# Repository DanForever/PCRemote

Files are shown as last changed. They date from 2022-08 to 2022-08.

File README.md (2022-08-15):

# Remote control ATX power switch

An alternative, Internet of things (IoT) approach to Wake-on-Lan (WoL).

This is a device that you plug into a free USB2 motherboard header in order to draw power (assuming that your motherboard continues to provides power to the USB headers when turned off), and sits inbetween the motherboard front panel IO header and your case.
It will connect to your wifi, and you can access it using your web browser, and press a button to remote turn your PC on or off.

This was created for people for whom WoL isn't an option, but need to be able to check and control the power status of their PC remotely (such as people that work from home using some form of remote desktop software).

WoL works by broadcasting a special packet containing the mac address of the PC you want to turn on. Until your PC starts responding to normal requests, you don't actually know if the WoL packet worked or not, and you have no way of checking if your PC is functioning.
This device on the other hand, can tell you at a glance if your PC is on or off. There's less ambiguity involved.

## Prototype
This is the first prototype, made entirely using THT parts
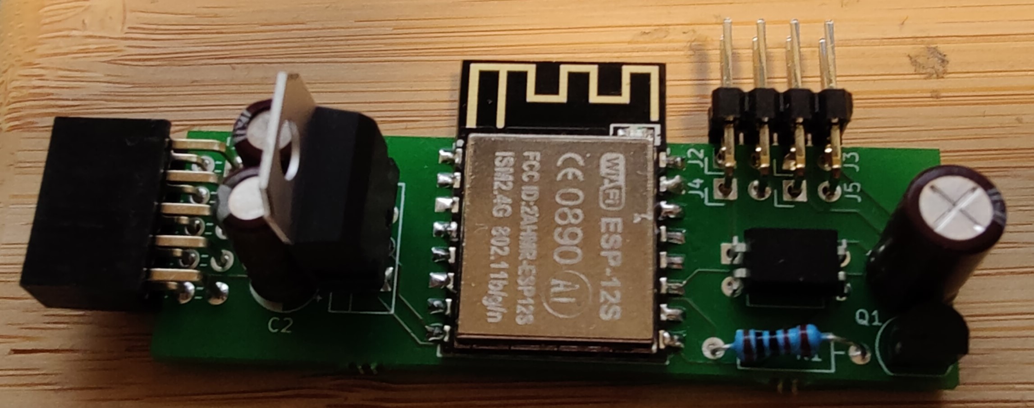
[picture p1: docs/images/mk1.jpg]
mk1


## Prerequisites
### [ESPTool](https://github.com/espressif/esptool "Esptool")
This is for flashing the firmware and the filesystem to the microcontroller
### [Arduino-CLI](https://github.com/arduino/arduino-cli)
To compile the firmware
Also requires these libraries:
* [ESP8266WiFi](https://github.com/esp8266/Arduino)
 * [ESP8266WebServer](https://github.com/esp8266/Arduino/tree/master/libraries/ESP8266WebServer)
  * [EEPROM](https://github.com/esp8266/Arduino/tree/master/libraries/EEPROM)
  * [LittleFS](https://github.com/esp8266/Arduino/tree/master/libraries/LittleFS)
* [ArduinoJson](https://arduinojson.org/)
* [StreamUtils](https://github.com/bblanchon/ArduinoStreamUtils)
* [DF-Print](https://github.com/DanForever/DF-Print)

### [mklittlefs](https://github.com/earlephilhower/mklittlefs)
This is for creating the filesystem binary

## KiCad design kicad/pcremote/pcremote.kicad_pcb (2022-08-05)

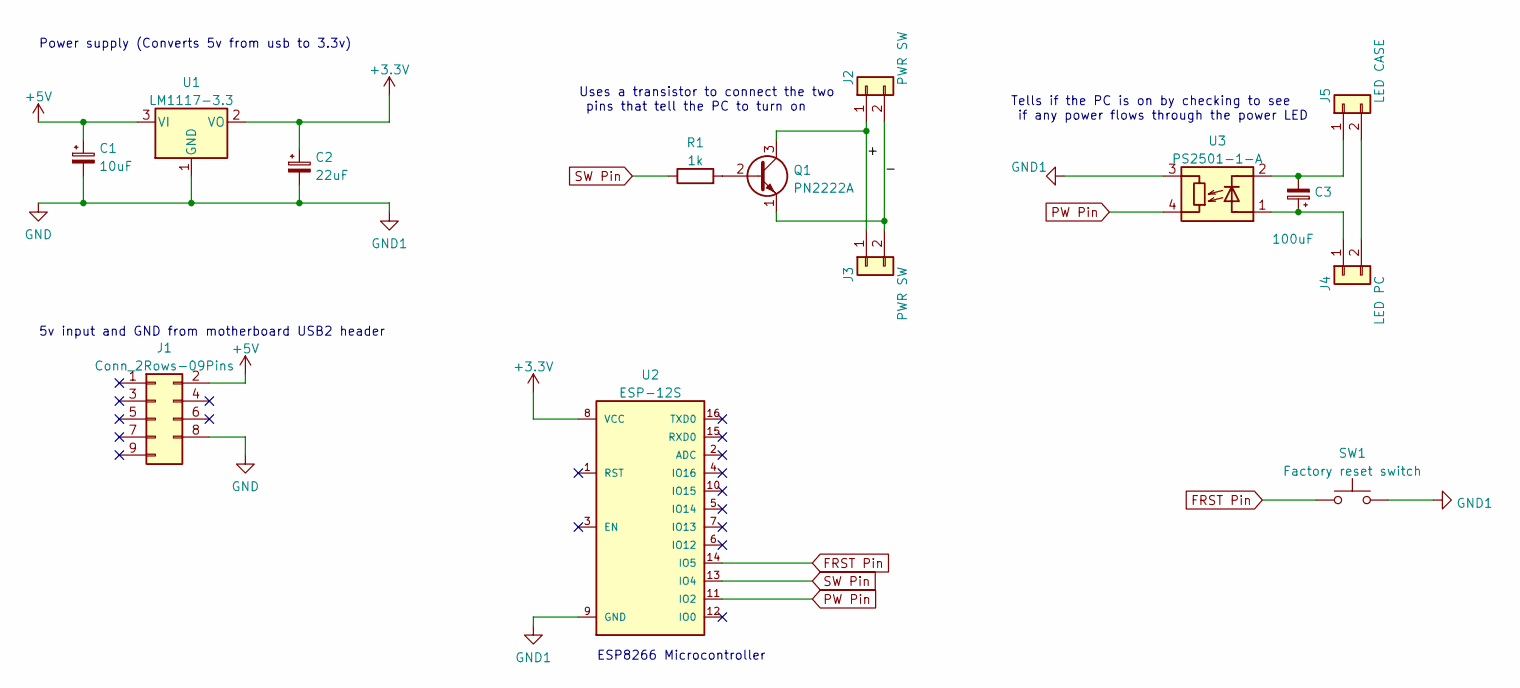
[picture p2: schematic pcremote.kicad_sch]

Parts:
C1: 10uF; CP_Radial_D5.0mm_P2.50mm
C2: 22uF; CP_Radial_D5.0mm_P2.50mm
C3: 100uF; CP_Radial_D5.0mm_P2.50mm
J1: Conn_2Rows-09Pins; PinSocket_2x05_P2.54mm_Horizontal
J2, J3: PWR SW; PinHeader_1x02_P2.54mm_Horizontal
J4: LED PC; PinHeader_1x02_P2.54mm_Horizontal
J5: LED CASE; PinHeader_1x02_P2.54mm_Horizontal
Q1: PN2222A; TO-92_Inline
R1: 1k; R_Axial_DIN0207_L6.3mm_D2.5mm_P10.16mm_Horizontal
SW1: Factory reset switch; SW_PUSH_6mm
U1: LM1117-3.3; TO-220-3_Vertical
U2: ESP-12S
U3: PS2501-1-A; DIP-4_W7.62mm

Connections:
+3.3V: C2.1, U1.2 (VO), U2.8 (VCC)
+5V: C1.1, J1.2, U1.3 (VI)
/+: J2.1, J3.1, Q1.3 (C)
/-: J2.2, J3.2, Q1.1 (E)
FRST Pin: SW1.1, U2.14 (IO5)
GND: C1.2, C2.2, J1.8, SW1.2, U1.1 (GND), U2.9 (GND), U3.3 (R)
unnamed: C3.1, J4.1, U3.1 (A)
unnamed: C3.2, J5.1, U3.2 (K)
unnamed: J4.2, J5.2
unnamed: Q1.2 (B), R1.2
PW Pin: U2.11 (IO2), U3.4 (R)
SW Pin: R1.1, U2.13 (IO4)

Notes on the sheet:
5v input and GND from motherboard USB2 header
ESP8266 Microcontroller
Uses a transistor to connect the two pins that tell the PC to turn on
Power supply (Converts 5v from usb to 3.3v)
Tells if the PC is on by checking to see if any power flows through the power LED

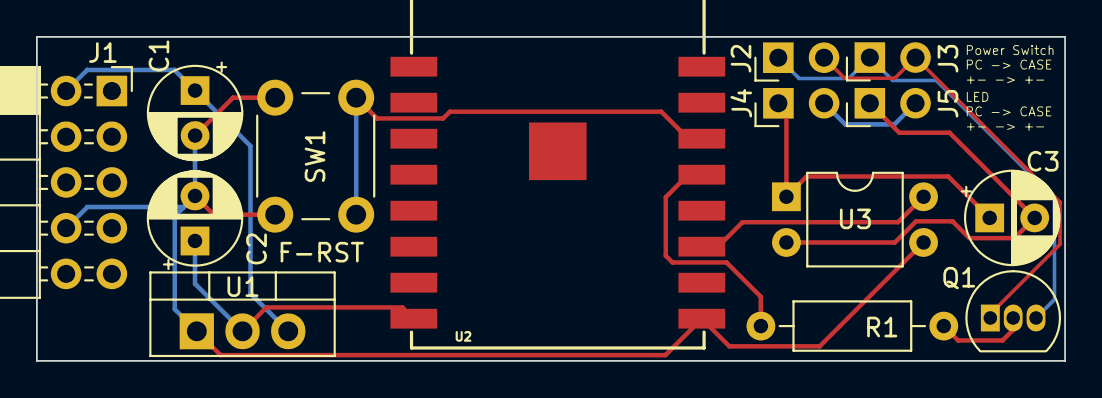
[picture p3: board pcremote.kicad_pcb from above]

Board: 2 copper layers, 57.1 x 18.0 mm, 14 parts (0 on the bottom side), 12 nets.

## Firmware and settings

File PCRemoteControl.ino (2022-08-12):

#include "src/WebServer/WebServer.h"
#include "src/Filesystem/filesystem.h"
#include "src/Configuration/configuration.h"
#include "src/Computer/Computer.h"
#include "src/Device/device.h"
#include "src/Debug/DebugPrint.h"

WebServer webServer;

void setup()
{
	Serial.begin(115200);
	//Serial.setDebugOutput(true);

	DEBUG_PRINTLN("");
	DEBUG_PRINTLN("Initializing...");

	g_Computer.Initialize();
	Filesystem::Initialize();
	g_Config.Initialize();
	g_device.Initialize();
	webServer.Start();

	DEBUG_PRINTLN("Ready");
}

void loop()
{
	webServer.Update();
	g_Computer.Update();
}

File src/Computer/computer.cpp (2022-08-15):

/*
* PC Remote
* Firmware for an IOT-device that can remotely press the power switch
* of an ATX style PC as well as monitor its current power state (on/off)
* https://github.com/DanForever/PCRemote
* Copyright (C) 2022 Daniel Neve
*
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
* You should have received a copy of the GNU General Public License
* along with this program.  If not, see <https://www.gnu.org/licenses/>.
*/

#include "computer.h"

#include <Arduino.h>
#include <DF-Print.h>

#define MICROCONTROLLER_LED_PIN 16

#define POWER_LED_PIN 2
#define POWER_SWITCH_PIN 4

void Computer::Initialize()
{
	pinMode(MICROCONTROLLER_LED_PIN, OUTPUT);

	pinMode(POWER_SWITCH_PIN, OUTPUT);
	digitalWrite(POWER_SWITCH_PIN, LOW);

	pinMode(POWER_LED_PIN, INPUT_PULLUP);
}

void Computer::PressPowerButton(unsigned long duration)
{
	DEBUG_PRINTLN("Power button pressed");

	m_pressRequested = true;
	m_targetPressDuration = duration;
	m_pressTimestamp = millis();
	digitalWrite(POWER_SWITCH_PIN, HIGH);
}

void Computer::Update()
{
	UpdatePowerButton();
	UpdatePowerCheck();
}

void Computer::UpdatePowerButton()
{
	if (m_pressRequested)
	{
		const unsigned long now = millis();
		const unsigned long currentPressDuration = now - m_pressTimestamp;

		if (currentPressDuration > m_targetPressDuration)
		{
			DEBUG_PRINTLN("Power button released");
			digitalWrite(POWER_SWITCH_PIN, LOW);
			m_pressRequested = false;
		}
	}
}

void Computer::UpdatePowerCheck()
{
	m_isPowerOn = digitalRead(POWER_LED_PIN) == LOW;

	if (m_isPowerOn)
		digitalWrite(MICROCONTROLLER_LED_PIN, HIGH);
	else
		digitalWrite(MICROCONTROLLER_LED_PIN, LOW);
}

Computer g_Computer;

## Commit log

2022-08-05 Initial checkin
    Contains the first working prototype of the remote control atx power switch
    [configuration.h, pcremote.kicad_pcb, pcremote.kicad_sch]
2022-08-10 Create PCRemoteControl.ino
    The root .ino missing from the original checkin
    [PCRemoteControl.ino]
2022-08-11 Support for credentials
    Digest Authentication, supports both SHA-256 as well as basic MD5 (can switch to SHA256 when chrome finally supports it)
    [configuration.h]
2022-08-12 Replaced Serial.print with a more user friendly set of debug print functions
    [PCRemoteControl.ino, computer.cpp]
2022-08-15 Refactored to use DF-Print
    Removed DebugPrint.h, as all the functionality is now published as a separate library

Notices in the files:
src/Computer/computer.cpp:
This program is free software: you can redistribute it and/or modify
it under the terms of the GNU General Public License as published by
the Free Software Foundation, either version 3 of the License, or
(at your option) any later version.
